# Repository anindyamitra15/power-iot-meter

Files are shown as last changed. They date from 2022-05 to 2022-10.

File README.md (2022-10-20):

# Iot Enabled Power Meter
Client server model for real-time monitoring of power usage aimed to simplify and modernise power usage readings and subsequent billing. Server backend handled by Firebase and Frontend made as a dynamic web app with angular framework. This project aims to elevate the process of power metering to modern connected standards and is primarily aimed towards power utility companies such that they may modernise their metering devices and enable them to be connected to the internet, allowing realtime monitoring and other advanced features like automated billing, remote disconnection, power outage detection and much more!  
The primary focus points of this project is simplicity, ease of installation of module, cost efficiency and rich user experience. 

## Documentation:
Slideshow presentation of the project highlighting the prominent topics discussed is available [here](https://docs.google.com/presentation/d/1IoBsD3WG-SK9_eWFI1Uqt-yPBRw3dVxrFmFgWGnbJ7E/edit?usp=sharing).  
The [documentation](https://docs.google.com/document/d/1lsBinQPk2TXrA8E3_NlRT1Esq-xPcBFSQFjI79IAyAw/edit?usp=sharing) for the research conducted and subsequent issues addressed has been made available.  
[Dataflow logic](https://whimsical.com/data-flow-XnRbm9PbMYaVgHn5g6pd81) and [Firmware Algorithm Logic](https://whimsical.com/firmware-algorithm-PJ4HBDd6Cb4NwG5o3SaENn) flowcharts are also provided.
Project Term Paper available [here](https://docs.google.com/document/d/1HhWOn-NgjPpBc6PuhfizeNlCIJG0mVvy1hvxCMSfRlQ/edit?usp=sharing).  
Short Infographic video showcasing the project and primary discussion points is available [here](https://www.youtube.com/watch?v=jMkZ5F2Xh4k).

## Folder Structure:
```
./
  |-- power-iot-meter-fe (the frontend dashboard)
  --- power-iot-meter-hw (the firmware sketch)
```

## Tools used:
- Angular
- Platform IO
- Espressif ESP32
- Arduino Framework
- Firebase RTDB
- Firebase Auth
- KiCAD

## Languages Used: 
- C/C++
- JS/TS

## Members:
- Arnab Das - [@arnabdas01](https://github.com/arnabdas01) 
- Anindya Kanti Mitra - [@anindyamitra15](https://github.com/anindyamitra15) 
- Rishav Dutta - [@randomdelta6](https://github.com/RandomDelta6) 
- Anubhav Dutta - [@anubhav666](https://github.com/anubhav666)

## Acknowledgement:
- This project has been developed under the guidance of [Dr. Bandana Barman](https://kgec.edu.in/department?name=ece).

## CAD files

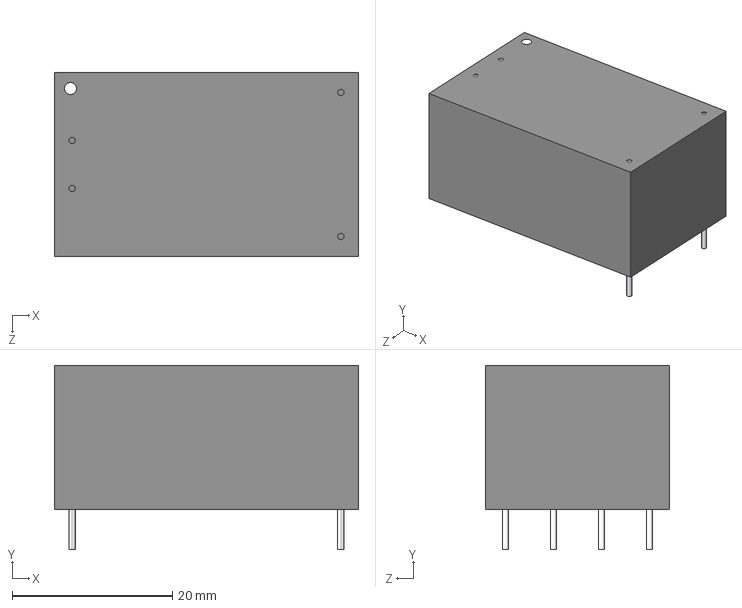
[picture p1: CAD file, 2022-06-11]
power-iot-meter-pcb/HLK-5M05/HLK-5M05.step
38.0 x 23.0 x 23.0 mm

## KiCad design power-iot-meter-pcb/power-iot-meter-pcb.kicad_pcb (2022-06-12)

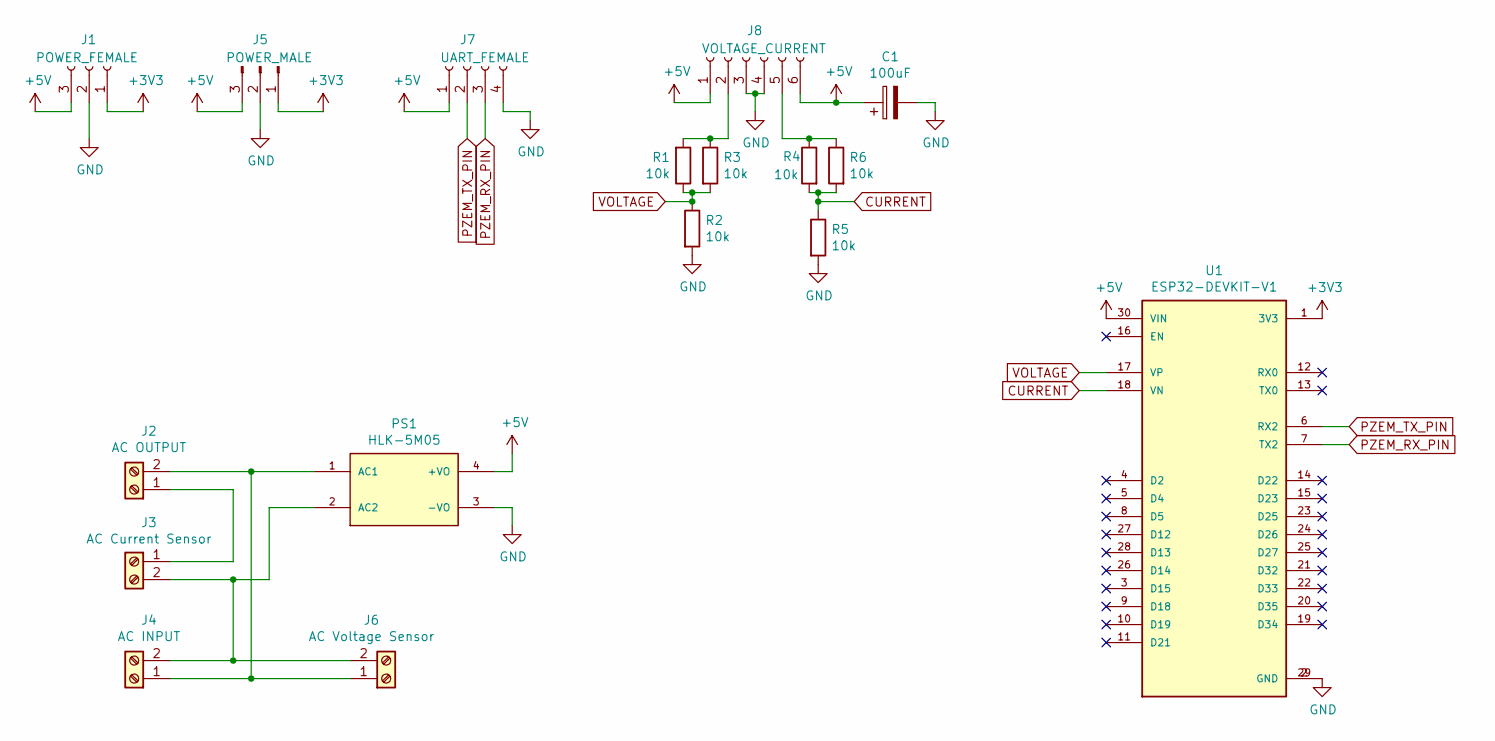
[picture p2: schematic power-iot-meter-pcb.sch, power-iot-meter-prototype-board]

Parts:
C1: 100uF; CP_Radial_D8.0mm_P3.50mm
J1: POWER_FEMALE; PinSocket_1x03_P2.00mm_Vertical
J2: AC OUTPUT; TerminalBlock_Altech_AK300-2_P5.00mm
J3: AC Current Sensor; SolderWire-0.5sqmm_1x02_P4.6mm_D0.9mm_OD2.1mm_Relief
J4: AC INPUT; TerminalBlock_Altech_AK300-2_P5.00mm
J5: POWER_MALE; PinHeader_1x03_P2.00mm_Vertical
J6: AC Voltage Sensor; SolderWire-0.5sqmm_1x02_P4.6mm_D0.9mm_OD2.1mm_Relief
J7: UART_FEMALE; PinSocket_1x04_P2.00mm_Vertical
J8: VOLTAGE_CURRENT; PinSocket_1x06_P2.00mm_Vertical
PS1: HLK-5M05; CONV_HLK-5M05; PARTREV N/A
R1, R2, R3, R4, R5, R6: 10k; R_Axial_DIN0207_L6.3mm_D2.5mm_P10.16mm_Horizontal
U1: ESP32-DEVKIT-V1; MODULE_ESP32_DEVKIT_V1; PARTREV N/A

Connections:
+3V3: J1.1, J5.1, U1.1 (3V3)
+5V: C1.1, J1.3, J5.3, J7.1, J8.1, J8.6, PS1.4 (+VO), U1.30 (VIN)
CURRENT: R4.2, R5.1, R6.2, U1.18 (VN)
GND: C1.2, J1.2, J5.2, J7.4, J8.3, J8.4, PS1.3 (-VO), R2.2, R5.2, U1.2 (GND), U1.29 (GND)
unnamed: J2.1, J3.1
unnamed: J2.2, J4.1, J6.1, PS1.1 (AC1)
unnamed: J3.2, J4.2, J6.2, PS1.2 (AC2)
unnamed: J8.2, R1.2, R3.1
unnamed: J8.5, R4.1, R6.1
PZEM_RX_PIN: J7.3, U1.7 (TX2)
PZEM_TX_PIN: J7.2, U1.6 (RX2)
VOLTAGE: R1.1, R2.1, R3.2, U1.17 (VP)

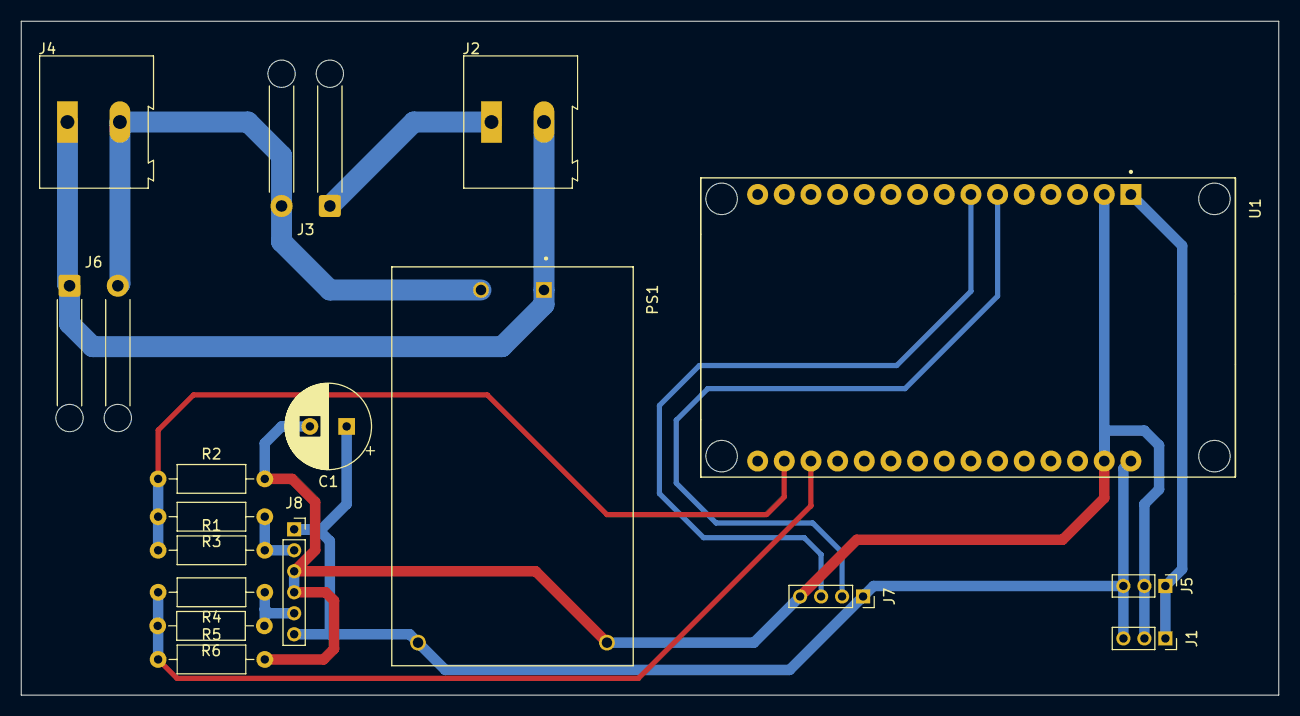
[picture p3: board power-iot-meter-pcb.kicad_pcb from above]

Board: 2 copper layers, 119.8 x 64.2 mm, 17 parts (0 on the bottom side), 12 nets.

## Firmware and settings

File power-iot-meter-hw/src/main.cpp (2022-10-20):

#include <Arduino.h>
#include <SPI.h>
#include <SPIFFS.h>
#include <MinimalWifiManager.h>
#include <ArduinoJson.h>
#include <FirebaseHandler.h>
#include <HardwarePropModule.h>

#define DEBUGGING

#define SCHEDULE(and_logic, num, delay) \
  if (and_logic && (millis() - last_time[num] > delay))
#define SCHEDULES 2
#define TSK_FETCH 200 // ms
#define TSK_SYNC 5000

String fetchPowerOutagesFromFirebase();
void pushStatsToFirebase(packet_t *);

AsyncWebServer server(80);
MinimalWifiManager wifi;
String power_outages;
packet_t data;
bool power_cut_occurred = false;

void setup()
{
  Serial.begin(115200);
  Serial.println("setup()");
  wifi.begin(&server, SPIFFS);
  // // wifi.resetSettings();
  wifi.autoConnect();
  set_time_from_ntp();
  firebaseHandler.begin(SPIFFS);
  firebaseHandler.firebase_connect();
  // attach();
  // FileOperation::listDir(SPIFFS);
  Serial.println("Exiting setup().. \nEntering loop()...");
}

void loop()
{
  static unsigned long last_time[SCHEDULES] = {0};
  wifi.loop();
  /**
   * @brief
   * Create a scheduler for Firebase fetch and push
   * fetch
   * calculate
   * push
   *
   */
  SCHEDULE(true, 0, TSK_FETCH)
  {
    bool power_good = fetchSensorData(&data);
    if (power_good)
    {
      if (power_cut_occurred)
      {
        Serial.println("Power restored...");
        String end_time = getTimestamp();
        String start_time = powerCutTimeFetch(SPIFFS);
        FirebaseJson json;
        json.setJsonData(fetchPowerOutagesFromFirebase());
        json.add<String, String>(start_time, end_time);
        firebaseHandler.updateData("/" + firebaseHandler.getUid() + "/power_outages", &json);
        power_cut_occurred = false;
      }
    }
    else
    {
      if (!power_cut_occurred)
      {
        Serial.println("Power cut occurred...");
        powerCutTimeStore(SPIFFS);
        power_cut_occurred = true;
      }
    }
    last_time[0] = millis();
  }

  SCHEDULE(true, 1, TSK_SYNC)
  {
    if(!power_cut_occurred)
      pushStatsToFirebase(&data);
    last_time[1] = millis();
  }
  // // on power cut
  // if (checkPowerCut() && !power_cut_occurred)
  // {
  //   Serial.println("Power cut occurred...");
  //   powerCutTimeStore(SPIFFS);
  //   power_cut_occurred = true;
  // }

  // // on power restore
  // if (power_cut_occurred && !checkPowerCut())
  // {
  //   Serial.println("Power restored...");
  //   String end_time = getTimestamp();
  //   String start_time = powerCutTimeFetch(SPIFFS);
  //   FirebaseJson json;
  //   json.setJsonData(fetchPowerOutagesFromFirebase());
  //   json.add<String, String>(start_time, end_time);
  //   firebaseHandler.updateData("/" + firebaseHandler.getUid() + "/power_outages", &json);
  //   power_cut_occurred = false;
  // }
}

String fetchPowerOutagesFromFirebase()
{
  power_outages = firebaseHandler.fetchData("/" + firebaseHandler.getUid() + "/power_outages");
#ifdef DEBUGGING
  Serial.println(power_outages);
#endif
  return power_outages;
}

void pushStatsToFirebase(packet_t *data)
{
  FirebaseJson json;
  // prepare to send all the data
  json.add<String, double>("apparent_power", data->apparent_power);
  json.add<String, double>("active_power", data->active_power);
  json.add<String, double>("voltage_rms", data->voltage_rms);
  json.add<String, double>("current_rms", data->current_rms);
  json.add<String, double>("power_factor", data->power_factor);
  json.add<String, double>("frequency", data->frequency);
  json.add<String, double>("total_energy", data->energy);
  json.add<String, String>("timestamp", data->timestamp);
  bool success = firebaseHandler.updateData("/" + firebaseHandler.getUid(), &json);
  Serial.println(success);
#ifdef DEBUGGING
  Serial.println(json.raw());
#endif
}

void updatePowerOutageLog(); // prepare json, check meter1 schema for reference

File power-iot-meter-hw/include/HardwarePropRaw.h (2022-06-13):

/**
 * @file HardwarePropRaw.h
 * @author @anindyamitra15 @RandomDelta6
 * @brief This will be measuring the voltage and current and deriving power from that
 * @version 0.1
 * @date 2022-06-06
 *
 * @copyright Copyright (c) 2022
 *
 */
#ifndef __HardwarePropRaw_H__
#define __HardwarePropRaw_H__
#include "Arduino.h"
#include "util.h"
#include "ZMPT101B.h"
#include "ACS712.h"

/**
 * @brief Pin definitions
 * TODO: To be decided Later
 */
#define VOLTAGE_PIN 36 // ANALOG PIN
#define CURRENT_PIN 39 // ANALOG PIN

#define POWER_FACTOR 0.8              // basically cos(36.8698)
#define REACTIVE_POWER_MULTIPLIER 0.6 // basically sin(36.8698)

ZMPT101B voltageSensor(VOLTAGE_PIN);
ACS712 currentSensor(CURRENT_PIN, 5.0, 1023, 100);

void attach()
{
    pinMode(VOLTAGE_PIN, INPUT);
    pinMode(CURRENT_PIN, INPUT);
    Serial.println("Calibrating... Ensure that no current flows through the sensor at this moment");
    voltageSensor.calibrate();
    currentSensor.autoMidPoint();
    delay(100);
    Serial.println("Done!");
}

void fetchSensorData(packet_t *data)
{
    // FIXME: implementation required after deciding on the sensors
}

void fetchSensorDataTest(packet_t *data)
{
    data->current_rms = data->current_rms + 1.073;
    if (data->current_rms > 20)
        data->current_rms = 2;
    data->voltage_rms = 220.0 + random(-300, 300) / 100.00;
    data->apparent_power = data->voltage_rms * data->current_rms;
    data->active_power = data->apparent_power * POWER_FACTOR;
}

#endif

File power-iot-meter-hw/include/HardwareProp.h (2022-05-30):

#ifndef __HardwareProp_H__
#define __HardwareProp_H__
#include "Arduino.h"
#include "util.h"

#define POWER_FACTOR 0.8              // basically cos(36.8698)
#define REACTIVE_POWER_MULTIPLIER 0.6 // basically sin(36.8698)
/**
 * @brief Pin definitions
 * TODO: To be decided Later
 */
#define CURRENT 0 // input pin
#define VOLTAGE 0 // output pin

void attach()
{
    pinMode(CURRENT, INPUT);
    pinMode(VOLTAGE, INPUT);
}

void fetchSensorData(packet_t *data)
{
    // FIXME: implementation required after deciding on the sensors
}

void fetchSensorDataTest(packet_t *data)
{
    data->max_peak_volt = 35.0;
    data->current_rms = 5.0;
    data->voltage_rms = 220.0;
    data->apparent_power = data->voltage_rms * data->current_rms;
    data->real_power = data->apparent_power * POWER_FACTOR;
}

#endif

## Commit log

2022-05-11 works ❤
2022-05-12 pass check implemented, works ♥
2022-06-06 user can see his/her device's data in real-time
2022-06-11 added PCB layout
    [HLK-5M05.step, power-iot-meter-pcb.kicad_pcb, power-iot-meter-pcb.sch]
2022-06-11 added page description
    [power-iot-meter-pcb.kicad_pcb, power-iot-meter-pcb.sch]
2022-06-12 PCB update
    [power-iot-meter-pcb.kicad_pcb, power-iot-meter-pcb.sch]
2022-06-13 added frequency and power factor support
2022-06-14 cghanges in schematic orientation
    [power-iot-meter-pcb.sch]
2022-10-20 power cut detection working
2023-08-22 Bump protobufjs from 6.11.3 to 6.11.4 in /power-iot-meter-fe
    Bumps [protobufjs](https://github.com/protobufjs/protobuf.js) from 6.11.3 to 6.11.4.
    - [Release notes](https://github.com/protobufjs/protobuf.js/releases)
    - [Changelog](https://github.com/protobufjs/protobuf.js/blob/master/CHANGELOG.md)
    - [Commits](https://github.com/protobufjs/protobuf.js/commits)
    ---
    updated-dependencies:
    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
